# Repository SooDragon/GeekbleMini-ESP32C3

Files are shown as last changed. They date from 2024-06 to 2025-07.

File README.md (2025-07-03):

GeekbleMini-ESP32C3
=============
GeekbleMini-ESP32C3 문서에 오신것을 환영합니다

아두이노 IDE에서 쉽게 사용할 수 있는 Geekble Mini를 통해 WiFi, Bluetooth 기능을 여러분의 프로젝트에 구현할 수 있습니다

Geekble Mini 핀맵
-------------
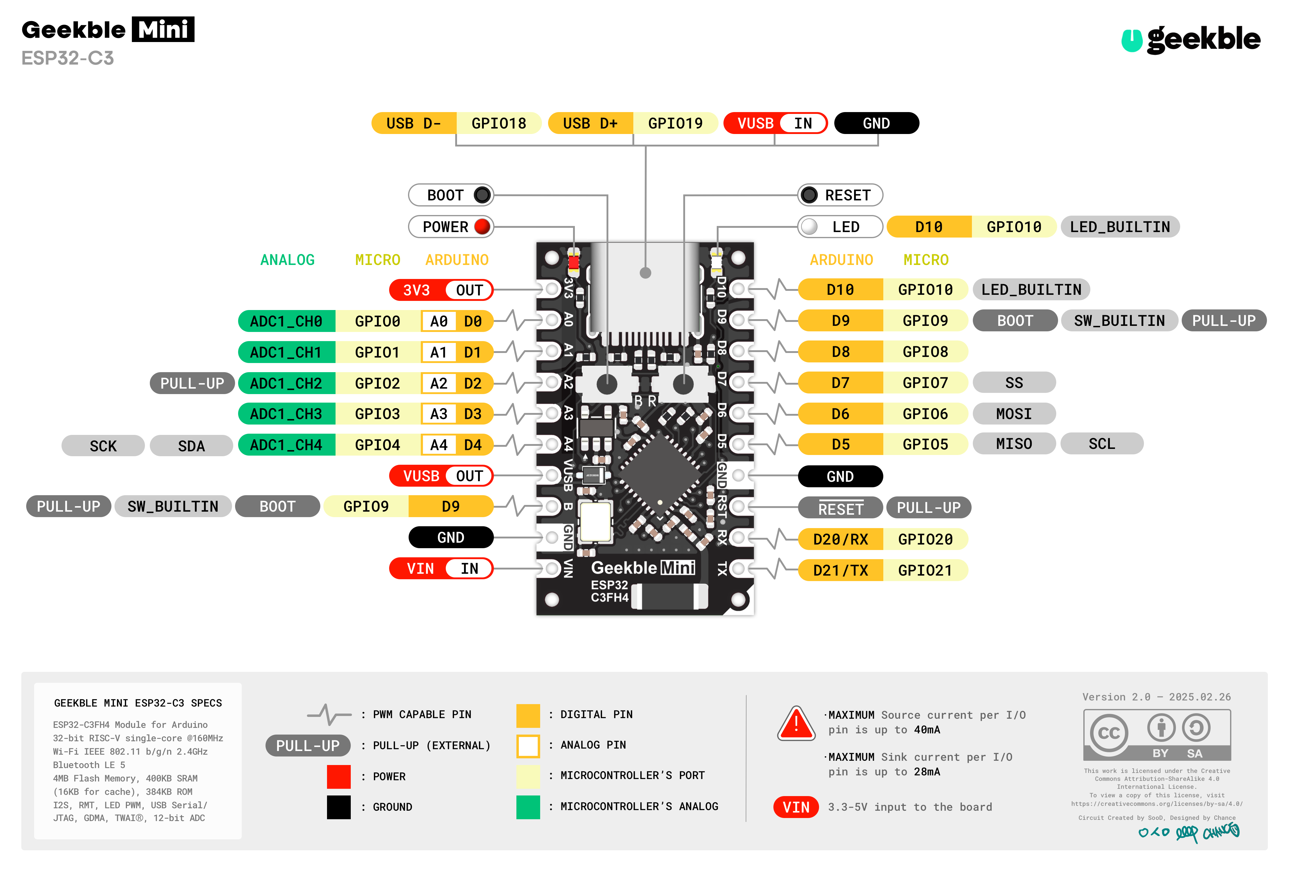
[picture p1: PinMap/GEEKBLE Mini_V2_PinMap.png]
GEEKBLE Mini-ESP32@2x

GeekbleMini PinMap

Geekble Mini 회로도
-------------
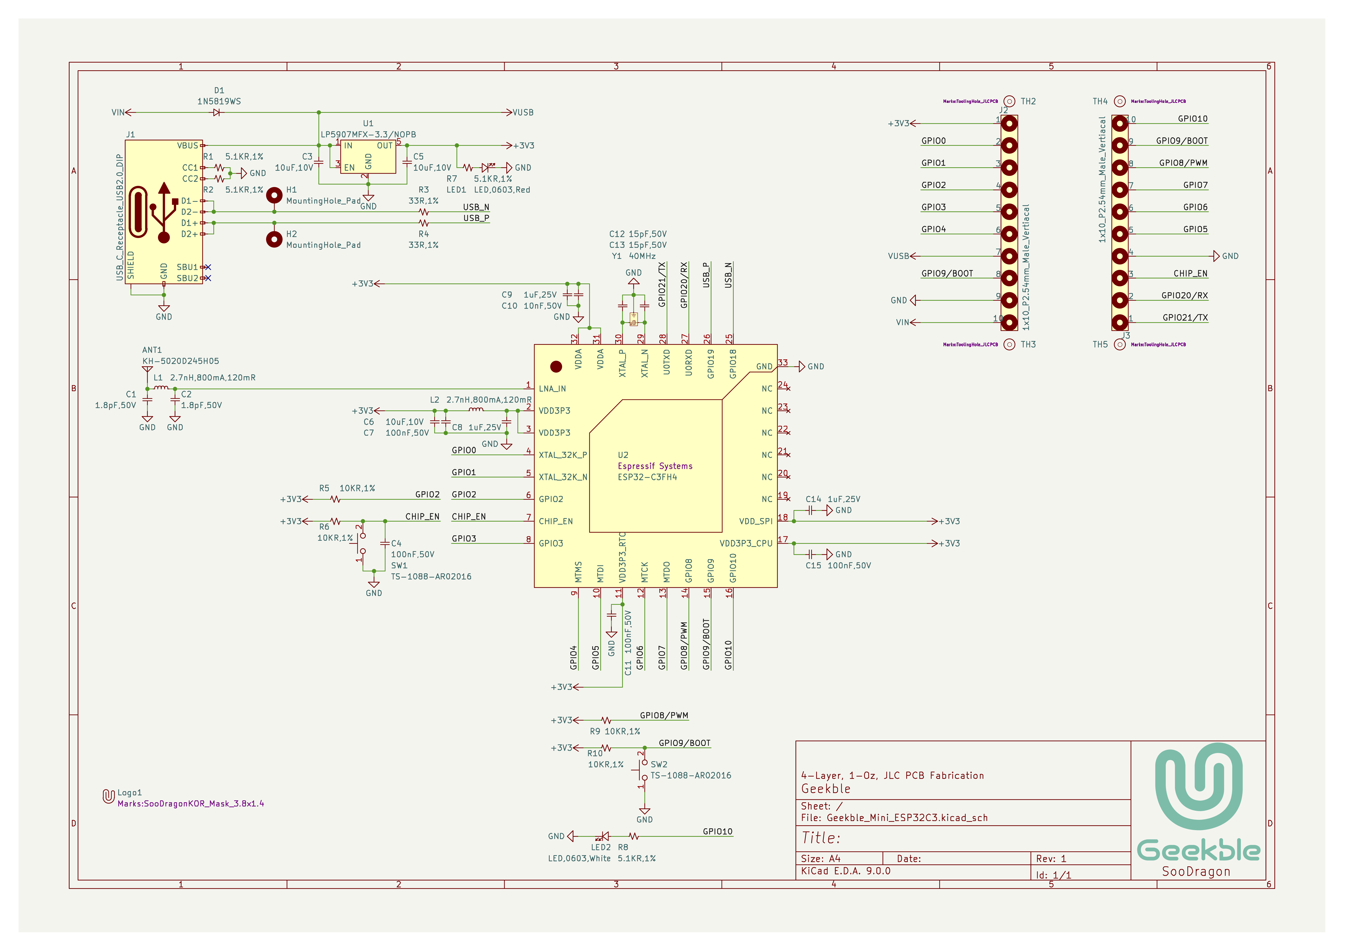
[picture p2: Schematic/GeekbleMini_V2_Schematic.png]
GeekbleMini Schematic

GeekbleMini Schematic

Geekble Mini 치수도
-------------
Dimension
GeekbleMini Dimension

Geekble Mini KiCad 라이브러리 by [@Alcyone-0022](https://github.com/Alcyone-0022)
-------------
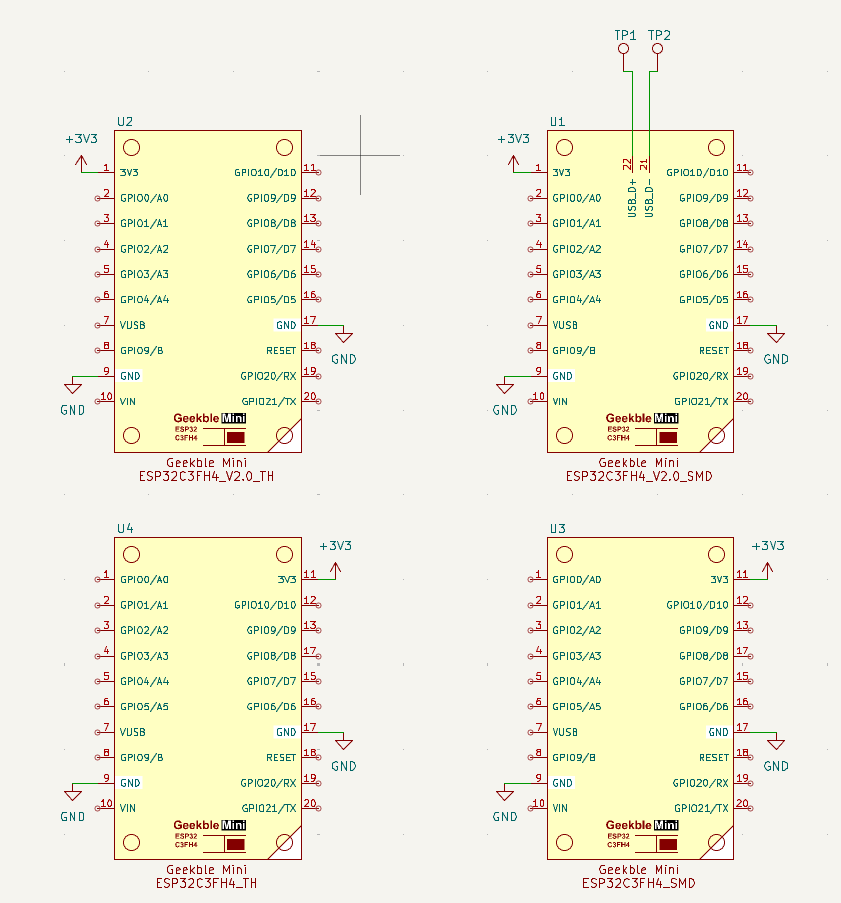
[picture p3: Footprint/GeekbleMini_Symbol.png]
Symbol
    
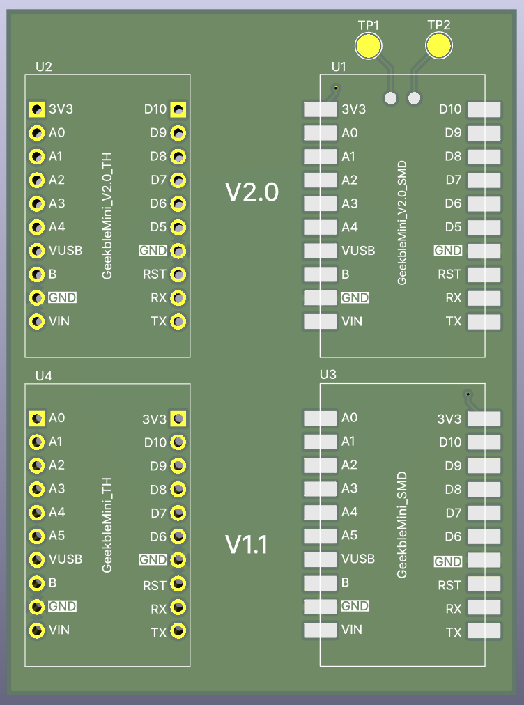
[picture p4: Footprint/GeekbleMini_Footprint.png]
Footprint
    
KiCad 프로젝트에 사용 가능한 Footprint가 존재합니다.    
**Geekble Mini ESP32C3FH4.pretty** 폴더와 **Geekble Mini ESP32C3FH4.kicad_sym** 파일을 KiCad 프로젝트 폴더에 옮긴 뒤,    
각각 풋프린트 에디터→파일→라이브러리 추가→프로젝트 선택→확인→**Geekble Mini ESP32C3FH4.pretty** 폴더 선택,    
심볼 에디터→파일→라이브러리 추가→프로젝트 선택→확인→**Geekble Mini ESP32C3FH4.kicad_sym** 파일 선택하여 추가하신 뒤 사용해 주세요.

Geekble Mini Version Log
-------------
- Ver.1.0.0: 최초 공개 버전
- Ver.1.1.0: Vin/VUSB 설계 변경, VUSB에서 Vin 방향으로 전류가 흐르지 않도록 회로 및 아트웍 수정, Vin에 배터리가 연결 된 상태에서 USB를 연결할 수 있다
- Ver.1.1.1: 핀헤더에 의해 실크가 가려지지 않게 배치 수정
- Ver.2.0: A5(ADC1)핀 D5핀으로 재배치, 재배치에 따른 핀 위치 수정

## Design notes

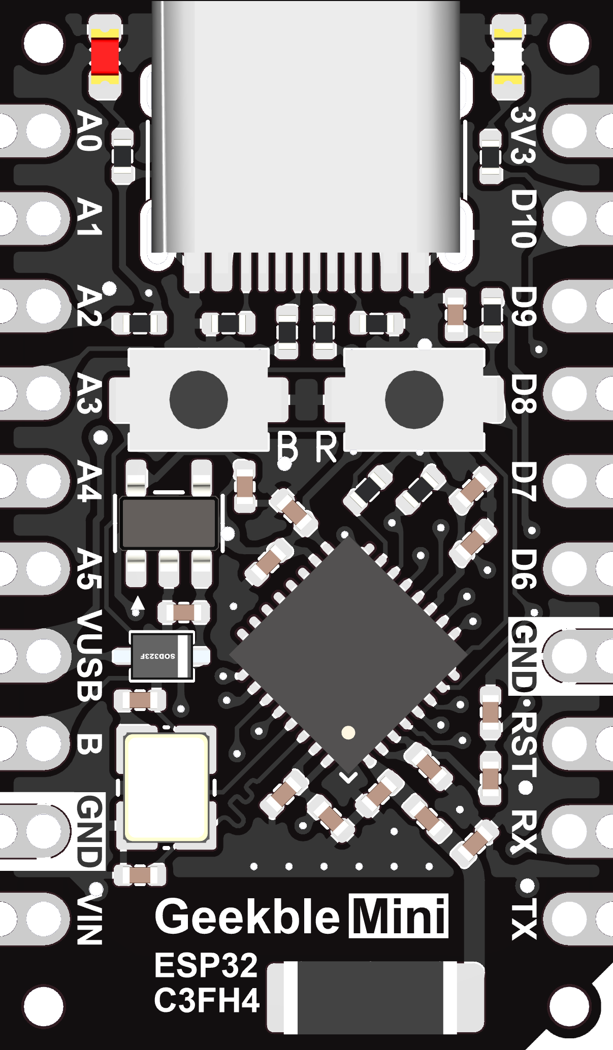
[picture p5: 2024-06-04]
GeekbleMini_V1_Diagram.png

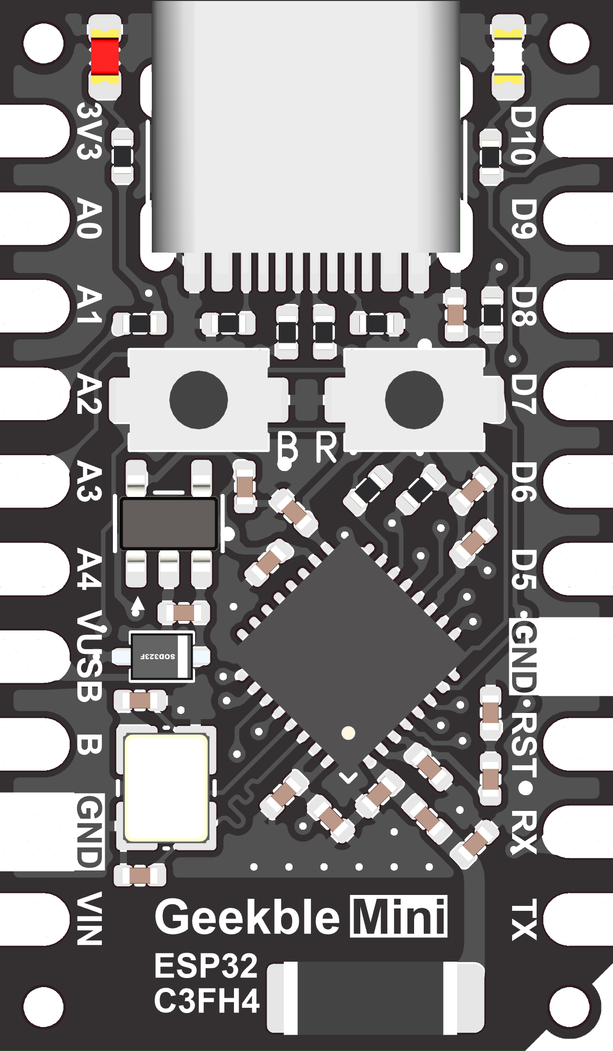
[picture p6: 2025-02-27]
Images/GeekbleMini_Ver.2.0_Diagram.png

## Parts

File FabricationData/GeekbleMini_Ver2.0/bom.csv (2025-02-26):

Designator | Footprint | Quantity | Value | LCSC Part #
ANT1 | ANT_5020 | 1 | KH-5020D245H05 | C45359218
C1, C2 | C_0402 | 2 | 1.8pF,50V | C327209
C10 | C_0402 | 1 | 10nF,50V | C15195
C11, C15, C4, C7 | C_0402 | 4 | 100nF,50V | C307331
C12, C13 | C_0402 | 2 | 15pF,50V | C1548
C14, C8, C9 | C_0402 | 3 | 1uF,25V | C52923
C3, C5, C6 | C_0402 | 3 | 10uF,10V | C386033
D1 | SOD-323F | 1 | 1N5819WS | C191023
H1, H2 | 1x1_1.0piPad_SMD | 2 | MountingHole_Pad
J1 | USB_DIP,8.94x7.3mm | 1 | USB_C_Receptacle_USB2.0_DIP | C165948
J2, J3 | 1x10_P2.54_CastellatedPad_PinHeader | 2 | 1x10_P2.54mm_Male_Vertiacal | C5383117
L1, L2 | L_0402 | 2 | 2.7nH,800mA,120mR | C77108
LED1 | LED_0603_Red | 1 | LED,0603,Red | C2286
LED2 | LED_0603_White | 1 | LED,0603,White | C2290
LOGO1 | SooDragonKOR_Mask_3.8x1.4 | 1 | Geekble_Logo
R1, R2, R7, R8 | R_0402 | 4 | 5.1KR,1% | C25905
R10, R5, R6, R9 | R_0402 | 4 | 10KR,1% | C25744
R3, R4 | R_0402 | 2 | 33R,1% | C25105
SW1, SW2 | TS-1088-AR020 | 2 | TS-1088-AR02016 | C720477
TH2, TH3, TH4, TH5 | ToolingHole_JLCPCB | 4 | ToolingHole
U1 | SOT-23-5 | 1 | LP5907MFX-3.3/NOPB | C80670
U2 | QFN-32-EP(5x5) | 1 | ESP32-C3FH4 | C2858491
Y1 | SMD-3225_4P | 1 | 40MHz | C9010

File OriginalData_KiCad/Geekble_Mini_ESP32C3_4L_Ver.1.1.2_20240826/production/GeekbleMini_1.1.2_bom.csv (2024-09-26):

Designator | Footprint | Quantity | Value | LCSC Part #
ANT1 | ANT_5020 | 1 | KH-5020D245M0X | C454142
C1, C2 | C_0402 | 2 | 1.8pF,50V | C327209
C10 | C_0402 | 1 | 10nF,50V | C15195
C11, C15, C4, C7 | C_0402 | 4 | 100nF,50V | C307331
C12, C13 | C_0402 | 2 | 15pF,50V | C1548
C14, C8, C9 | C_0402 | 3 | 1uF,25V | C52923
C3, C5, C6 | C_0402 | 3 | 10uF,10V | C386033
D1 | SOD-323F | 1 | 1N5819WS | C191023
J1 | USB_DIP,8.94x7.3mm | 1 | USB_C_Receptacle_USB2.0_DIP | C165948
L1, L2 | L_0402 | 2 | 2.7nH,500mA,100mR | C76791
LED1 | LED_0603_Red | 1 | LED,0603,Red | C2286
LED2 | LED_0603_White | 1 | LED,0603,White | C2290
R1, R2, R7, R8 | R_0402 | 4 | 5.1KR,1% | C25905
R10, R5, R6, R9 | R_0402 | 4 | 10KR,1% | C25744
R3, R4 | R_0402 | 2 | 33R,1% | C25105
SW1, SW2 | TS-1088-AR020 | 2 | TS-1088-AR02016 | C720477
U1 | SOT-23-5 | 1 | LP5907MFX-3.3/NOPB | C80670
U2 | QFN-32-EP(5x5) | 1 | ESP32-C3FH4 | C2858491
Y1 | SMD-3225_4P | 1 | 40MHz | C9010

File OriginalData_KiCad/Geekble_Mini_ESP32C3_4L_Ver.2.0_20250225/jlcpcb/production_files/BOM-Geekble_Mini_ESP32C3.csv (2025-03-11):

Comment | Designator | Footprint | LCSC | Quantity
10nF,50V | C10 | C_0402 | C15195 | 1
15pF,50V | C12,C13 | C_0402 | C1548 | 2
USB_C_Receptacle_USB2.0_DIP | J1 | USB_DIP,8.94x7.3mm | C165948 | 1
1N5819WS | D1 | SOD-323F | C191023 | 1
LED,0603,Red | LED1 | LED_0603_Red | C2286 | 1
LED,0603,White | LED2 | LED_0603_White | C2290 | 1
33R,1% | R3,R4 | R_0402 | C25105 | 2
10KR,1% | R10,R5,R6,R9 | R_0402 | C25744 | 4
5.1KR,1% | R1,R2,R7,R8 | R_0402 | C25905 | 4
ESP32-C3FH4 | U2 | QFN-32-EP(5x5) | C2858491 | 1
100nF,50V | C11,C15,C4,C7 | C_0402 | C307331 | 4
1.8pF,50V | C1,C2 | C_0402 | C327209 | 2
10uF,10V | C3,C5,C6 | C_0402 | C386033 | 3
KH-5020D245H05 | ANT1 | ANT_5020 | C45359218 | 1
1uF,25V | C14,C8,C9 | C_0402 | C52923 | 3
1x10_P2.54mm_Male_Vertiacal | J2,J3 | 1x10_P2.54_CastellatedPad_PinHeader | C5383117 | 2
TS-1088-AR02016 | SW1,SW2 | TS-1088-AR020 | C720477 | 2
2.7nH,800mA,120mR | L1,L2 | L_0402 | C77108 | 2
LP5907MFX-3.3/NOPB | U1 | SOT-23-5 | C80670 | 1
40MHz | Y1 | SMD-3225_4P | C9010 | 1
ToolingHole | TH4 | ToolingHole_JLCPCB |  | 1
ToolingHole | TH5 | ToolingHole_JLCPCB |  | 1
Geekble_Logo | Logo1 | SooDragonKOR_Mask_3.8x1.4 |  | 1
ToolingHole | TH3 | ToolingHole_JLCPCB |  | 1
ToolingHole | TH2 | ToolingHole_JLCPCB |  | 1
MountingHole_Pad | H2 | 1x1_1.0piPad_SMD |  | 1
MountingHole_Pad | H1 | 1x1_1.0piPad_SMD |  | 1

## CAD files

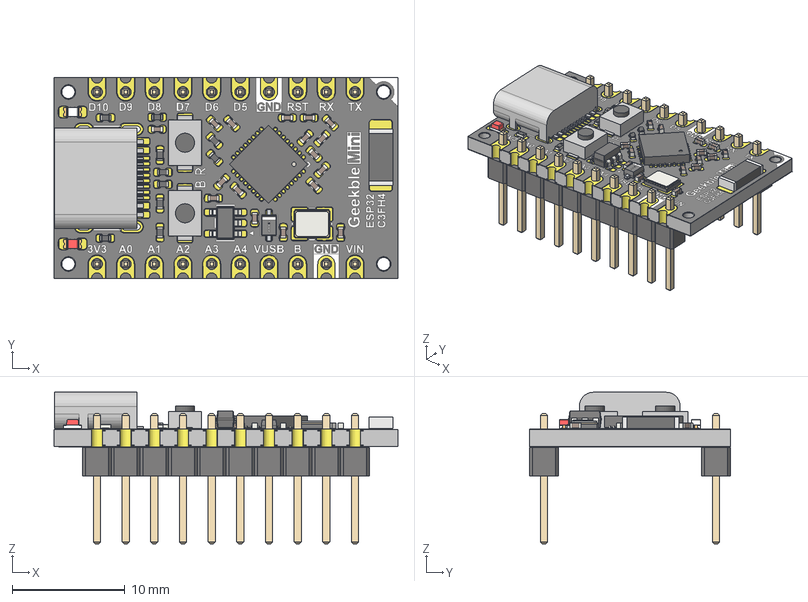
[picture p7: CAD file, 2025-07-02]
3D Model/GeekbleMini Ver2.0_PinHeader.step
30.5 x 17.8 x 13.4 mm
LED0603_WHITE
C_0402_1005Metric x 17
R_0402_1005Metric x 10
TS-1088-AR020 v2 x 2
QFN-32-1EP_5x5mm_P0.5mm_EP3.65x3.65mm
SOT-23-5
ANT_2050
SOD323F
HRO TYPE-C-31-M-12
Crystal_SMD_3225-4Pin_3.2x2.5mm
LED0603_RED
PinHeader_1x10_P2.54mm_Vertical x 2
Geekble_Mini_ESP32C3_copper
Geekble_Mini_ESP32C3_silkscreen
Geekble_Mini_ESP32C3_soldermask
Geekble_Mini_ESP32C3_PCB

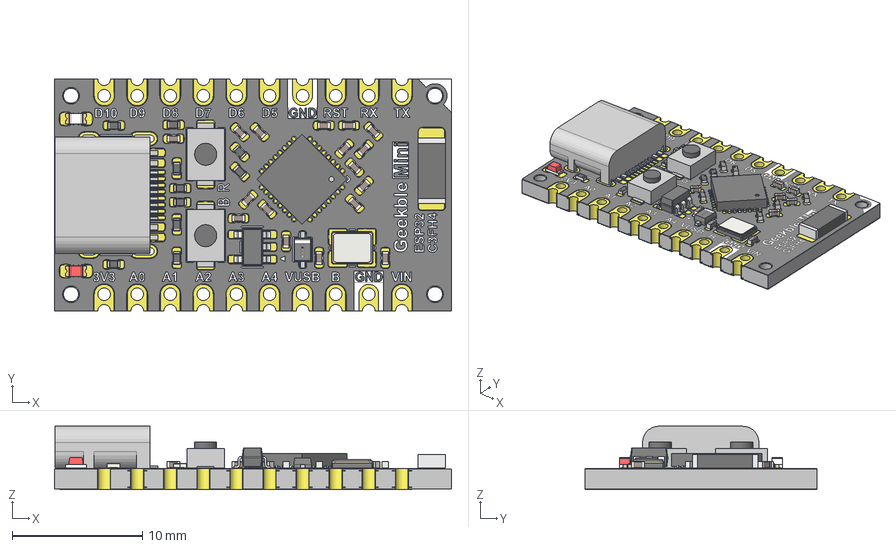
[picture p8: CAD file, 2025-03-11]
Footprint/GeekbleMini Ver2.0.step
30.5 x 17.8 x 4.89 mm
LED0603_WHITE
C_0402_1005Metric x 17
R_0402_1005Metric x 10
TS-1088-AR020 v2 x 2
QFN-32-1EP_5x5mm_P0.5mm_EP3.65x3.65mm
SOT-23-5
ANT_2050
SOD323F
HRO TYPE-C-31-M-12
Crystal_SMD_3225-4Pin_3.2x2.5mm
LED0603_RED
Geekble_Mini_ESP32C3_copper
Geekble_Mini_ESP32C3_silkscreen
Geekble_Mini_ESP32C3_soldermask
Geekble_Mini_ESP32C3_PCB

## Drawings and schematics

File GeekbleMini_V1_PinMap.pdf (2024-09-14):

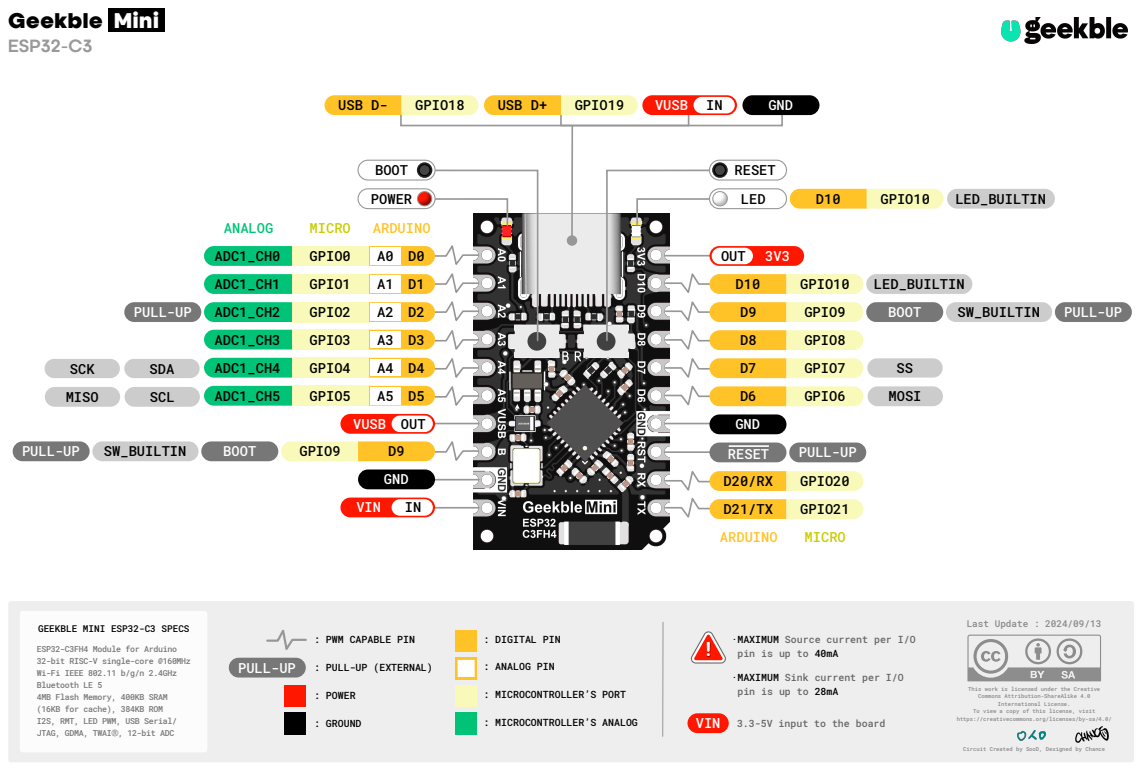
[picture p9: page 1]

GEEKBLE MINI ESP32-C3 SPECS
ESP32-C3FH4 Module for Arduino
32-bit RISC-V single-core @160MHz
Wi-Fi IEEE 802.11 b/g/n 2.4GHz
Bluetooth LE 5
4MB Flash Memory, 400KB SRAM
(16KB for cache), 384KB ROM
I2S, RMT, LED PWM, USB Serial/
JTAG, GDMA, TWAIⓇ, 12-bit ADC

·MAXIMUM Source current per I/O
pin is up to 40mA

·MAXIMUM Sink current per I/O
pin is up to 28mA

This work is licensed under the Creative
Commons Attribution-ShareAlike 4.0
International License.

To view a copy of this license, visit
https://creativecommons.org/licenses/by-sa/4.0/

Circuit Created by SooD, Designed by Chance

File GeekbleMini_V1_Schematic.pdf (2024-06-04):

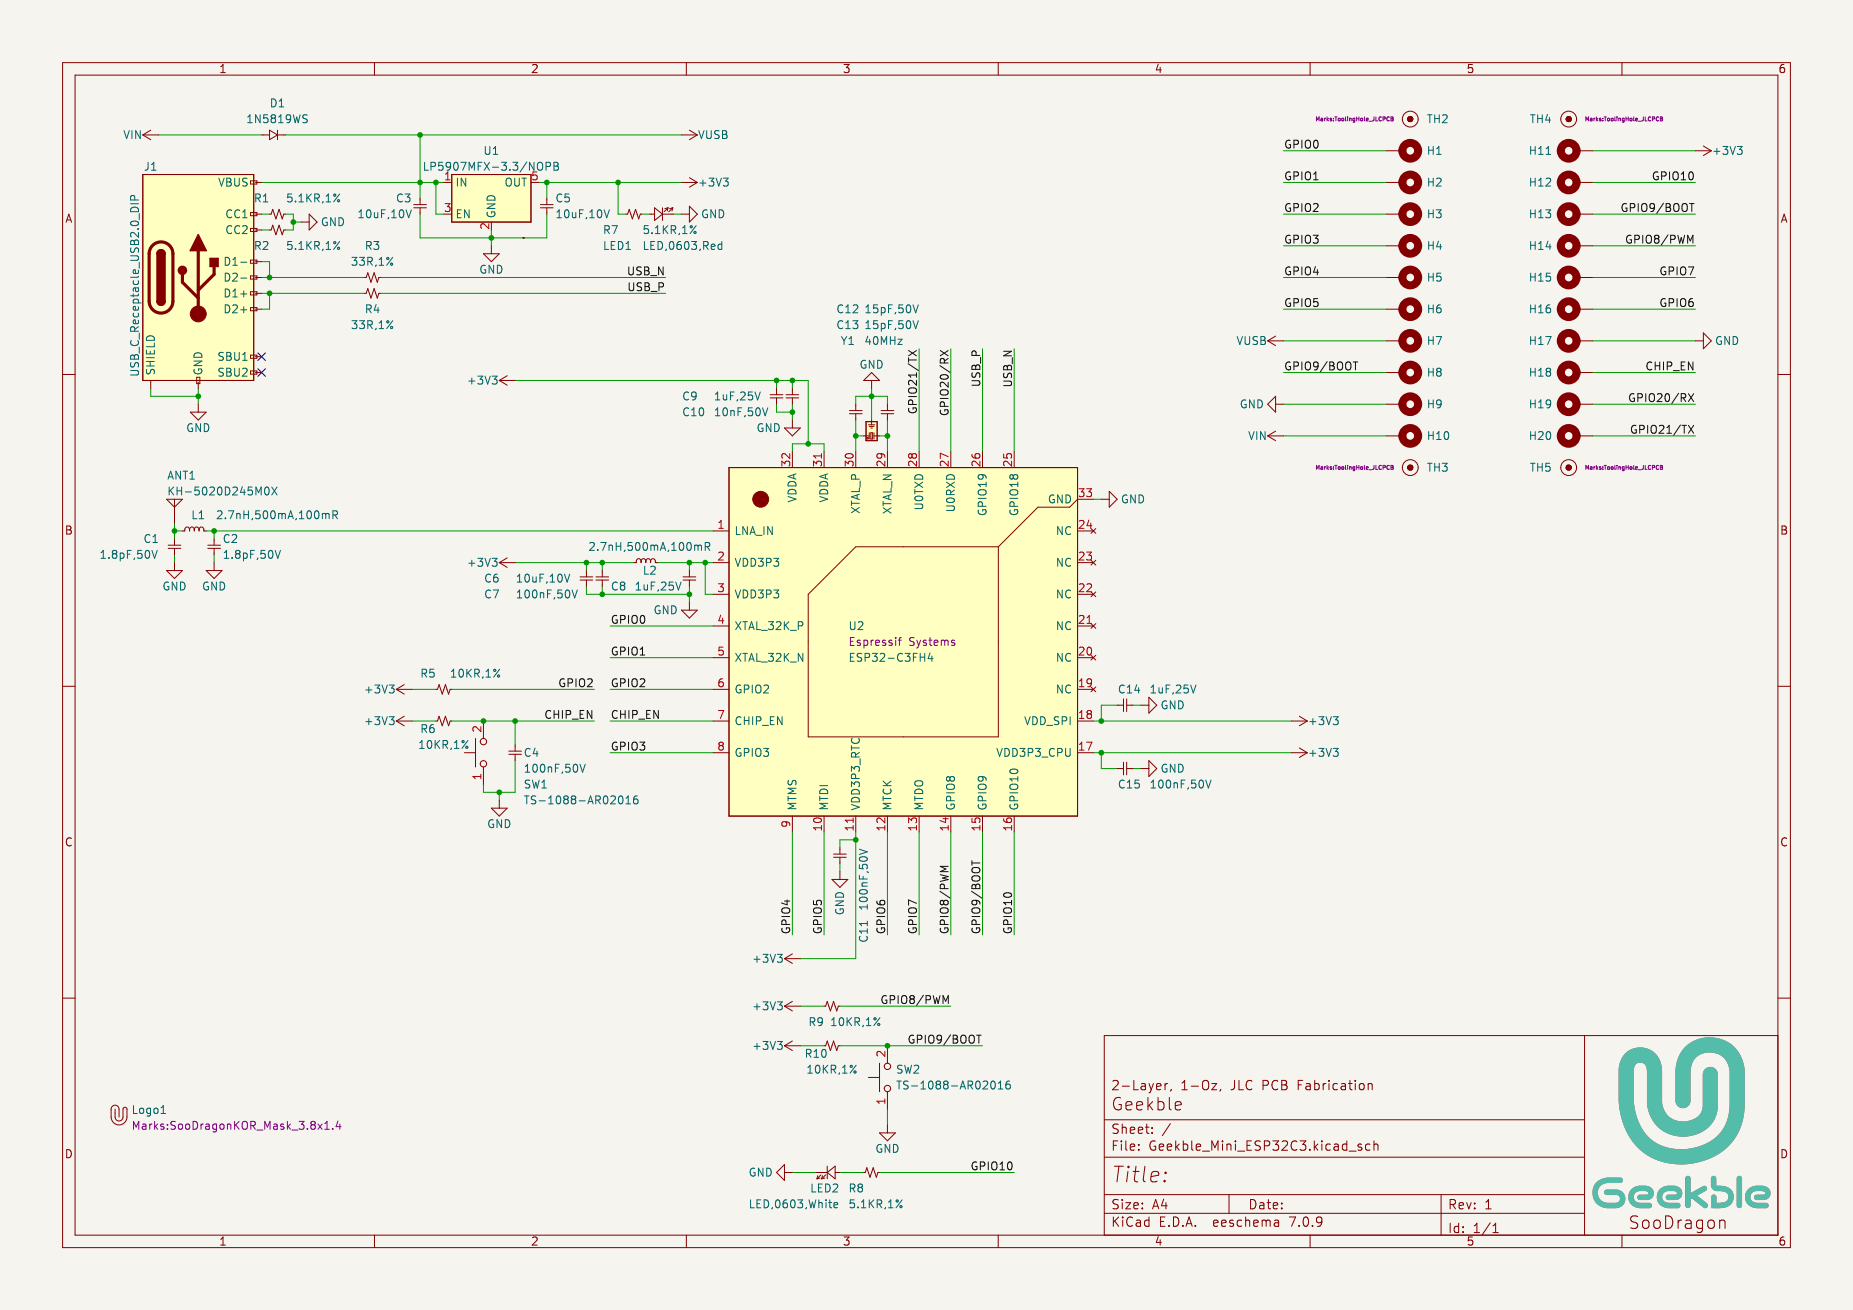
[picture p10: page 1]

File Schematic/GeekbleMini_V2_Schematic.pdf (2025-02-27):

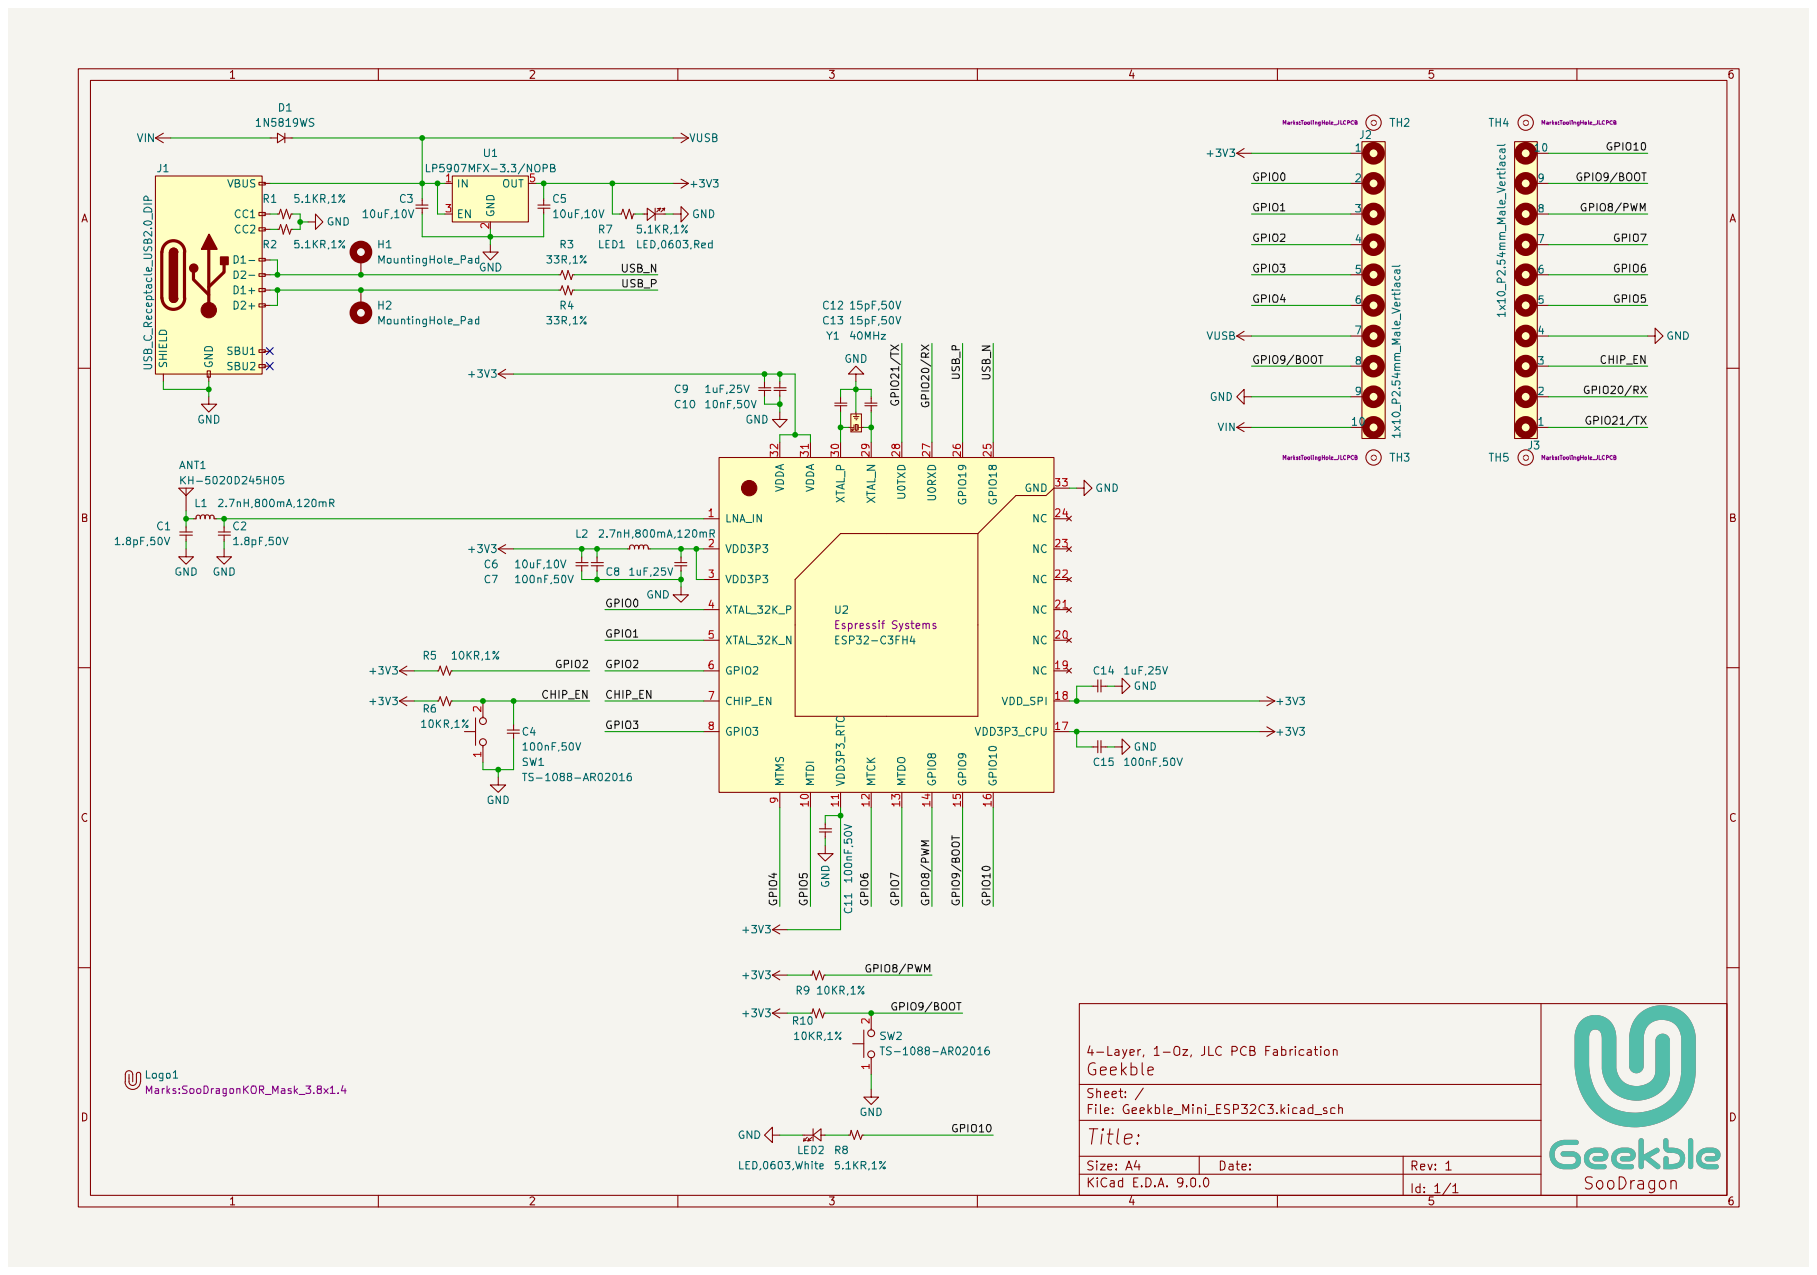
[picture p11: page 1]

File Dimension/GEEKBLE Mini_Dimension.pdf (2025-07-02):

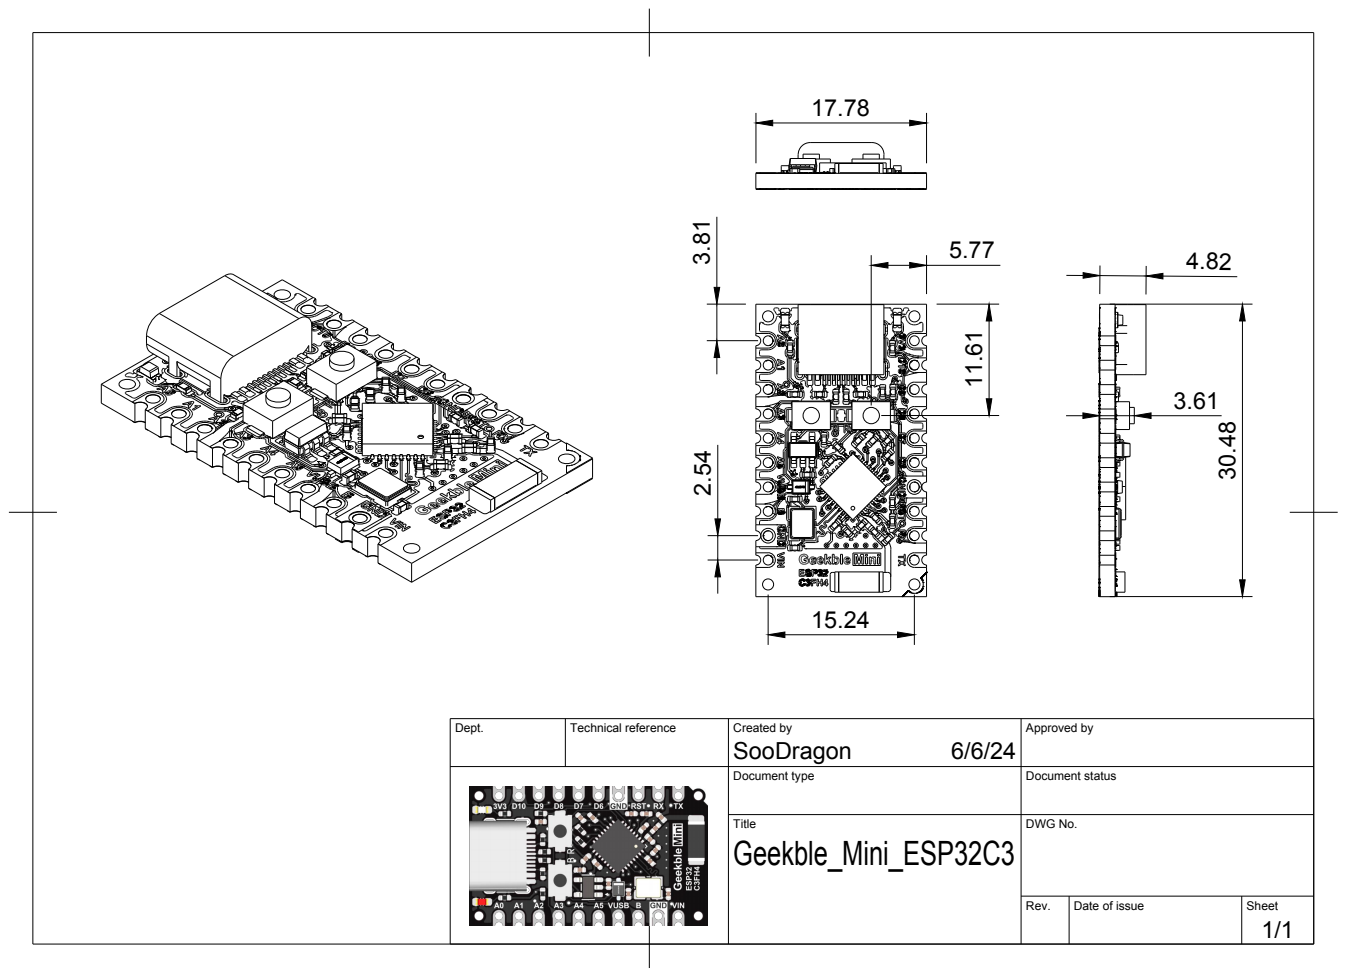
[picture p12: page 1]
Dept.; Technical reference; Created by; Approved by; Document type; Document status; Title; DWG No.; Rev.; Date of issue; Sheet

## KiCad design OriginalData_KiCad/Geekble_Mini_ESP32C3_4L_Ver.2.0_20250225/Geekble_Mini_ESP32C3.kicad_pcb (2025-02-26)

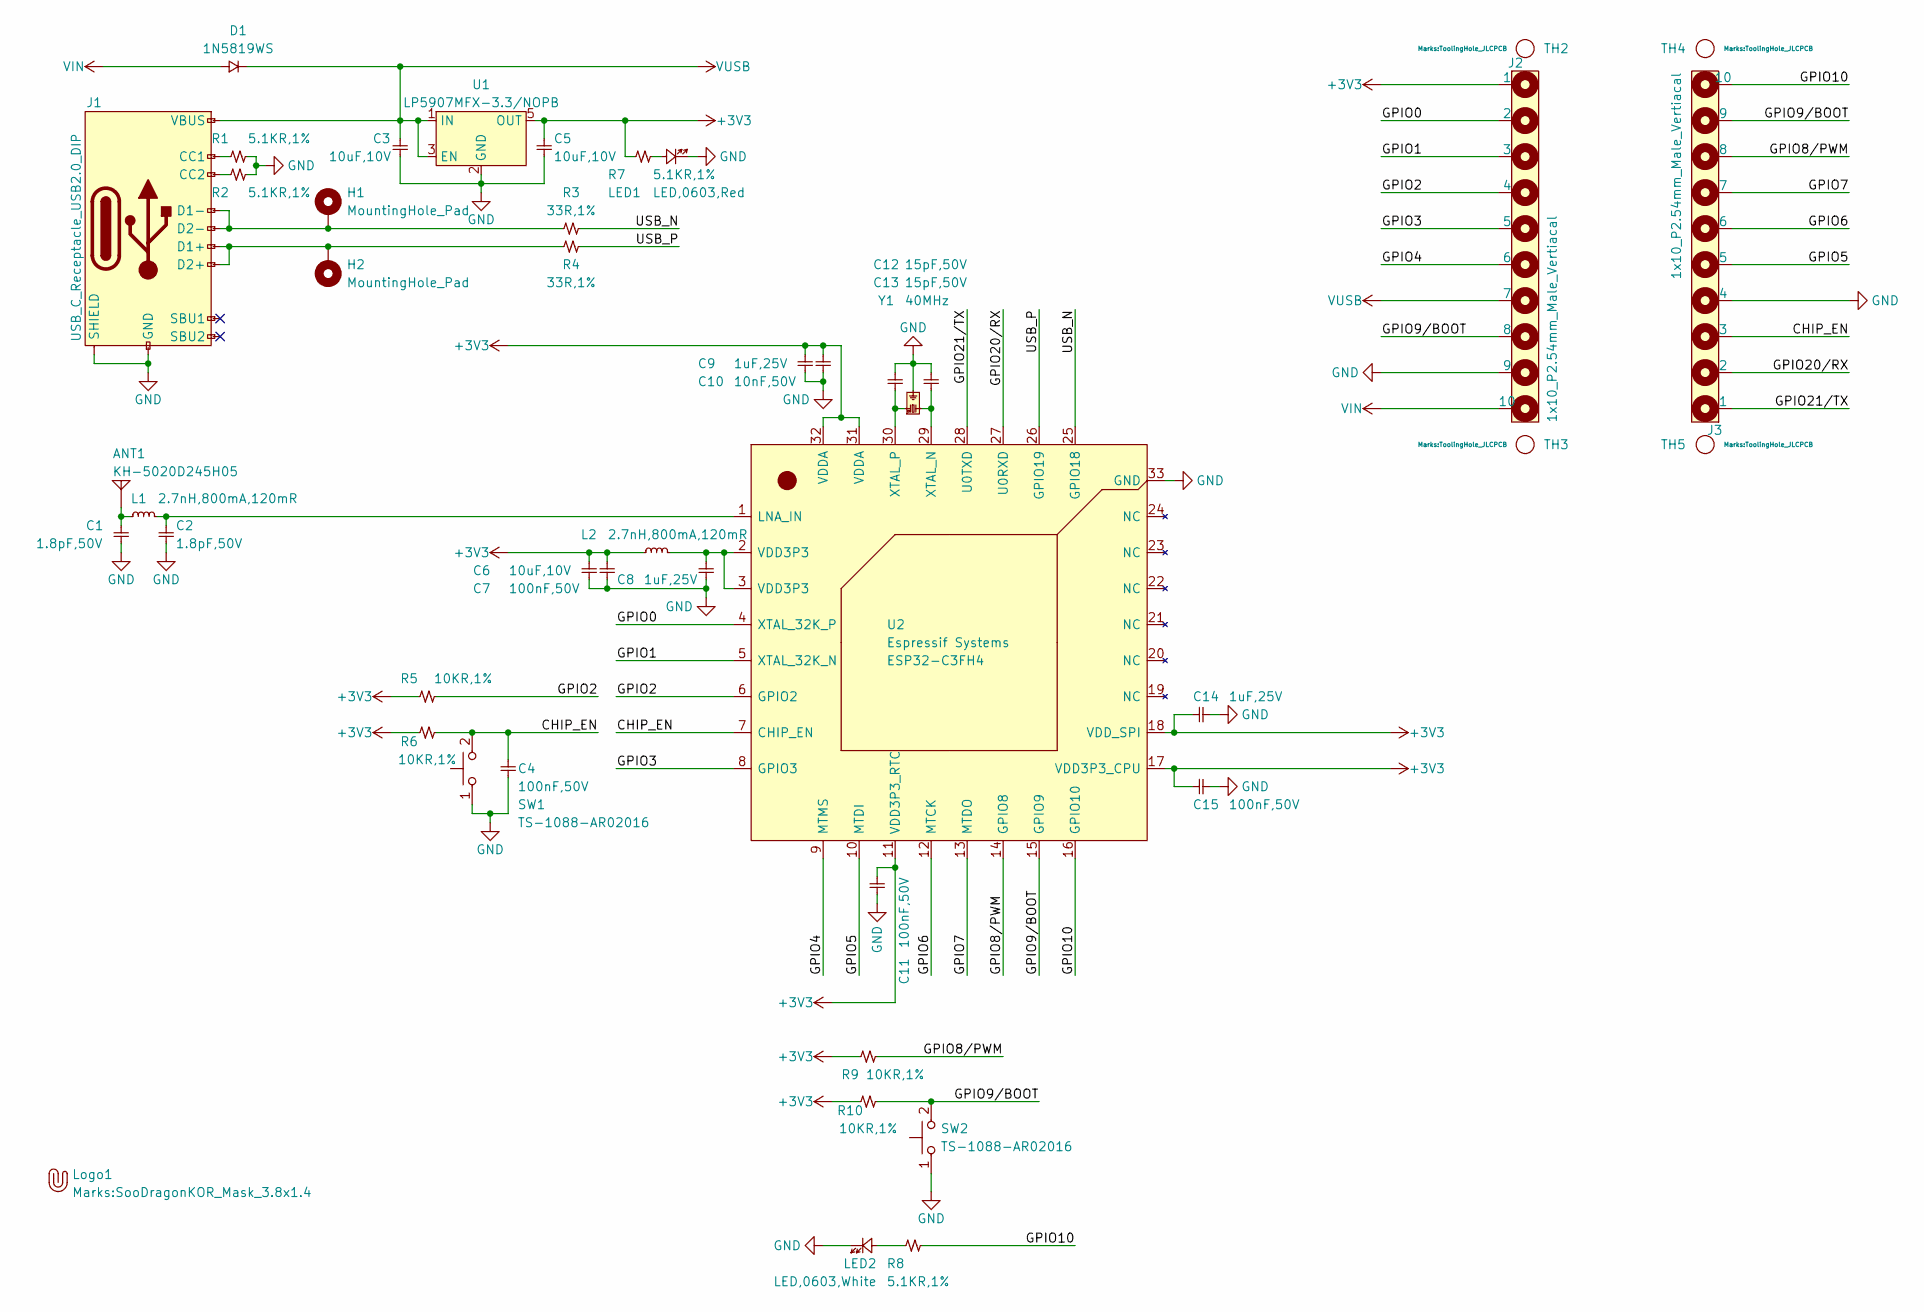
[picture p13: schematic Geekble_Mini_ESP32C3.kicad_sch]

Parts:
ANT1: KH-5020D245H05; ANT_5020; Manufacturer Part Number KH-5020D245H05; LCSC C45359218
C1, C2: 1.8pF,50V; C_0402; Manufacturer Part Number CC0402BRNPO9BN1R8; LCSC C327209
C3, C5, C6: 10uF,10V; C_0402; Manufacturer Part Number LDK105CBJ106MVLF; LCSC C386033
C4, C7, C11, C15: 100nF,50V; C_0402; Manufacturer Part Number CL05B104KB54PNC; LCSC C307331
C8, C9, C14: 1uF,25V; C_0402; Manufacturer Part Number CL05A105KA5NQNC; LCSC C52923
C10: 10nF,50V; C_0402; Manufacturer Part Number CL05B103KB5NNNC; LCSC C15195
C12, C13: 15pF,50V; C_0402; Manufacturer Part Number 0402CG150J500NT; LCSC C1548
D1: 1N5819WS; SOD-323F; Manufacturer Part Number 1N5819WS; LCSC C191023
H1, H2: MountingHole_Pad; 1x1_1.0piPad_SMD
J1: USB_C_Receptacle_USB2.0_DIP; USB_DIP,8.94x7.3mm; Manufacturer Part Number TYPE-C-31-M-12; LCSC C165948
J2, J3: 1x10_P2.54mm_Male_Vertiacal; 1x10_P2.54_CastellatedPad_PinHeader; Manufacturer Part Number 2541WV-10P; LCSC C5383117
L1, L2: 2.7nH,800mA,120mR; L_0402; Manufacturer Part Number LQG15HS2N7S02D; LCSC C77108
LED1: LED,0603,Red; LED_0603_Red; Manufacturer Part Number KT-0603R; LCSC C2286
LED2: LED,0603,White; LED_0603_White; LCSC C2290
Logo1: Geekble_Logo; SooDragonKOR_Mask_3.8x1.4
R1, R2, R7, R8: 5.1KR,1%; R_0402; Manufacturer Part Number 0402WGF5101TCE; LCSC C25905
R3, R4: 33R,1%; R_0402; Manufacturer Part Number 0402WGF330JTCE; LCSC C25105
R5, R6, R9, R10: 10KR,1%; R_0402; Manufacturer Part Number 0402WGF1002TCE; LCSC C25744
SW1, SW2: TS-1088-AR02016; TS-1088-AR020; Manufacturer Part Number TS-1088-AR02016; LCSC C720477
TH2, TH3, TH4, TH5: ToolingHole; ToolingHole_JLCPCB
U1: LP5907MFX-3.3/NOPB; SOT-23-5; Manufacturer Part Number LP5907MFX-3.3/NOPB; LCSC C80670
U2: ESP32-C3FH4; QFN-32-EP(5x5); Manufacturer Part Number ESP32-C3FH4; LCSC C2858491
Y1: 40MHz; SMD-3225_4P; Manufacturer Part Number X322540MPB4SI; LCSC C9010

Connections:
+3V3: C5.2, C6.2, C7.2, C9.2, C10.2, C11.2, C14.2, C15.2, J2.1, L2.1, R5.1, R6.1, R7.1, R9.1, R10.1, U1.5 (OUT), U2.11 (VDD3P3_RTC), U2.17 (VDD3P3_CPU), U2.18 (VDD_SPI), U2.31 (VDDA), U2.32 (VDDA)
/CHIP_EN: C4.2, J3.3, R6.2, SW1.2 (B), U2.7 (CHIP_EN)
/GPIO0: J2.2, U2.4 (XTAL_32K_P)
/GPIO1: J2.3, U2.5 (XTAL_32K_N)
/GPIO2: J2.4, R5.2, U2.6 (GPIO2)
/GPIO3: J2.5, U2.8 (GPIO3)
/GPIO4: J2.6, U2.9 (MTMS)
/GPIO5: J3.5, U2.10 (MTDI)
/GPIO6: J3.6, U2.12 (MTCK)
/GPIO7: J3.7, U2.13 (MTDO)
/GPIO8/PWM: J3.8, R9.2, U2.14 (GPIO8)
/GPIO9/BOOT: J2.8, J3.9, R10.2, SW2.2 (B), U2.15 (GPIO9)
/GPIO10: J3.10, R8.2, U2.16 (GPIO10)
/GPIO20/RX: J3.2, U2.27 (U0RXD)
/GPIO21/TX: J3.1, U2.28 (U0TXD)
/USB_N: R3.2, U2.25 (GPIO18)
/USB_P: R4.2, U2.26 (GPIO19)
GND: C1.1, C2.1, C3.1, C4.1, C5.1, C6.1, C7.1, C8.1, C9.1, C10.1, C11.1, C12.1, C13.1, C14.1, C15.1, J1.A1B12 (GND), J1.B1A12 (GND), J1.S1 (SHIELD), J1.S2 (SHIELD), J1.S3 (SHIELD), J1.S4 (SHIELD), J2.9, J3.4, LED1.C, LED2.C, R1.2, R2.2, SW1.1 (A), SW2.1 (A), U1.2 (GND), U2.33 (GND), Y1.2 (GND), Y1.4 (GND)
unnamed: ANT1.Feed, C1.2, L1.1
unnamed: C8.2, L2.2, U2.2 (VDD3P3), U2.3 (VDD3P3)
unnamed: J1.A5 (CC1), R1.1
unnamed: J1.B5 (CC2), R2.1
unnamed: H2.1, J1.A6 (D1+), J1.B6 (D2+), R4.1
unnamed: H1.1, J1.A7 (D1-), J1.B7 (D2-), R3.1
unnamed: LED1.A, R7.2
unnamed: LED2.A, R8.1
unnamed: C2.2, L1.2, U2.1 (LNA_IN)
unnamed: C13.2, U2.29 (XTAL_N), Y1.3 (OSC2)
unnamed: C12.2, U2.30 (XTAL_P), Y1.1 (OSC1)
VIN: D1.A, J2.10
VUSB: C3.2, D1.C, J1.A4B9 (VBUS), J1.B4A9 (VBUS), J2.7, U1.1 (IN), U1.3 (EN)

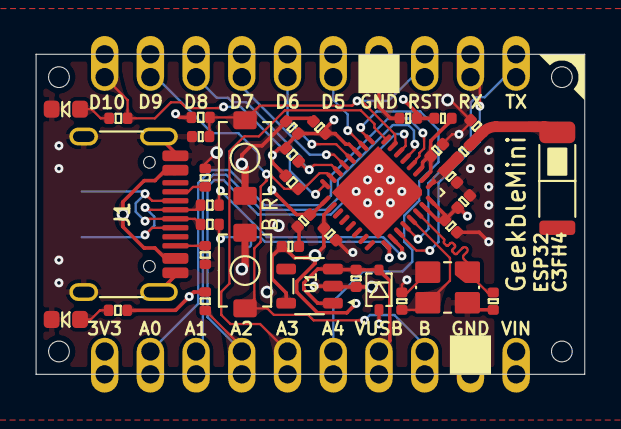
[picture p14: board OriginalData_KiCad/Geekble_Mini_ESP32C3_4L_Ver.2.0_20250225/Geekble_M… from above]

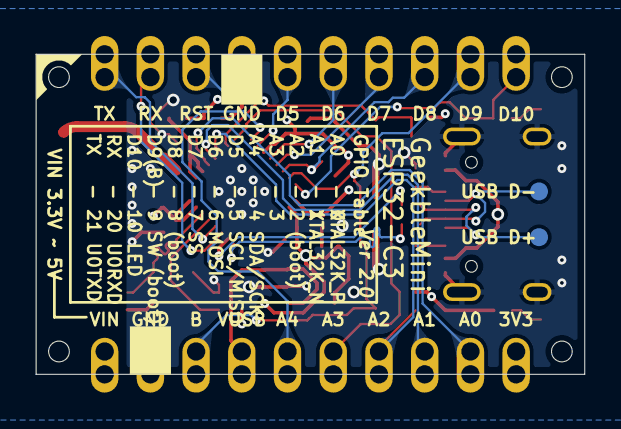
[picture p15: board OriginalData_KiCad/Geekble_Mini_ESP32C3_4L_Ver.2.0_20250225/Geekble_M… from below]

Board: 4 copper layers, 30.5 x 17.8 mm, 46 parts (4 on the bottom side), 31 nets.

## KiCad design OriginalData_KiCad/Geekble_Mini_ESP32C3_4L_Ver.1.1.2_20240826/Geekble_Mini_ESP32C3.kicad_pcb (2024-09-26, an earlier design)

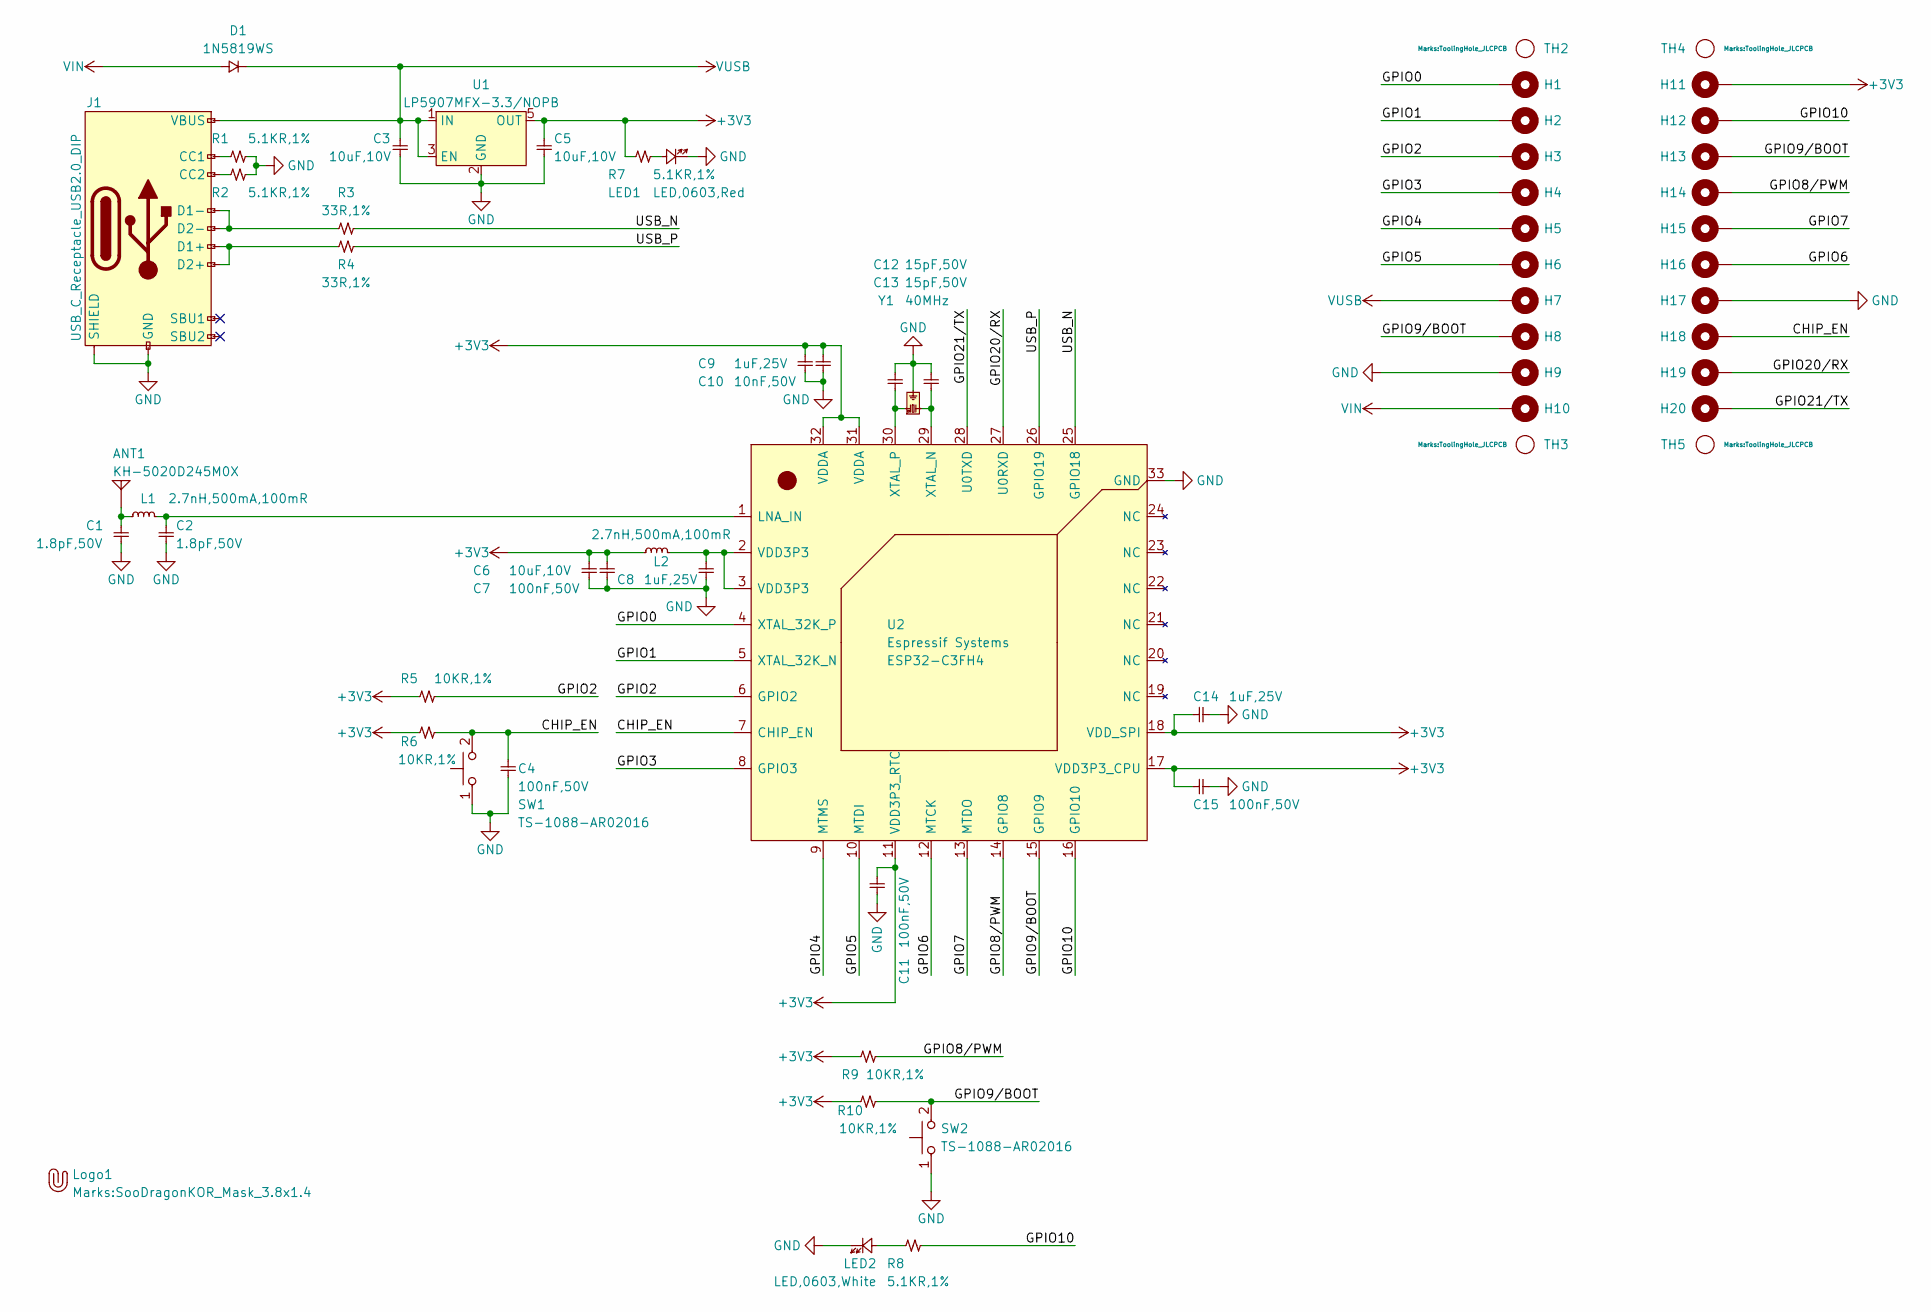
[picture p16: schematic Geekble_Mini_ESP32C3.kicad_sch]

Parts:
ANT1: KH-5020D245M0X; ANT_5020; Manufacturer Part Number KH-5020D245M0X; LCSC C454142
C1, C2: 1.8pF,50V; C_0402; Manufacturer Part Number CC0402BRNPO9BN1R8; LCSC C327209
C3, C5, C6: 10uF,10V; C_0402; Manufacturer Part Number LDK105CBJ106MVLF; LCSC C386033
C4, C7, C11, C15: 100nF,50V; C_0402; Manufacturer Part Number CL05B104KB54PNC; LCSC C307331
C8, C9, C14: 1uF,25V; C_0402; Manufacturer Part Number CL05A105KA5NQNC; LCSC C52923
C10: 10nF,50V; C_0402; Manufacturer Part Number CL05B103KB5NNNC; LCSC C15195
C12, C13: 15pF,50V; C_0402; Manufacturer Part Number 0402CG150J500NT; LCSC C1548
D1: 1N5819WS; SOD-323F; Manufacturer Part Number 1N5819WS; LCSC C191023
H1, H2, H3, H4, H5, H6, H7, H8, H9, H10, H11, H12, H13, H14, H15, H16, H17, H18, H19, H20: MountingHole_Pad; 1x1_P2.54_CastellatedPad
J1: USB_C_Receptacle_USB2.0_DIP; USB_DIP,8.94x7.3mm; Manufacturer Part Number TYPE-C-31-M-12; LCSC C165948
L1, L2: 2.7nH,500mA,100mR; L_0402; Manufacturer Part Number MLK1005S2N7ST000; LCSC C76791
LED1: LED,0603,Red; LED_0603_Red; Manufacturer Part Number KT-0603R; LCSC C2286
LED2: LED,0603,White; LED_0603_White; LCSC C2290
Logo1: Geekble_Logo; SooDragonKOR_Mask_3.8x1.4
R1, R2, R7, R8: 5.1KR,1%; R_0402; Manufacturer Part Number 0402WGF5101TCE; LCSC C25905
R3, R4: 33R,1%; R_0402; Manufacturer Part Number 0402WGF330JTCE; LCSC C25105
R5, R6, R9, R10: 10KR,1%; R_0402; Manufacturer Part Number 0402WGF1002TCE; LCSC C25744
SW1, SW2: TS-1088-AR02016; TS-1088-AR020; Manufacturer Part Number TS-1088-AR02016; LCSC C720477
TH2, TH3, TH4, TH5: ToolingHole; ToolingHole_JLCPCB
U1: LP5907MFX-3.3/NOPB; SOT-23-5; Manufacturer Part Number LP5907MFX-3.3/NOPB; LCSC C80670
U2: ESP32-C3FH4; QFN-32-EP(5x5); Manufacturer Part Number ESP32-C3FH4; LCSC C2858491
Y1: 40MHz; SMD-3225_4P; Manufacturer Part Number X322540MPB4SI; LCSC C9010

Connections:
+3V3: C5.2, C6.2, C7.2, C9.2, C10.2, C11.2, C14.2, C15.2, H11.1, L2.1, R5.1, R6.1, R7.1, R9.1, R10.1, U1.5 (OUT), U2.11 (VDD3P3_RTC), U2.17 (VDD3P3_CPU), U2.18 (VDD_SPI), U2.31 (VDDA), U2.32 (VDDA)
/CHIP_EN: C4.2, H18.1, R6.2, SW1.2 (B), U2.7 (CHIP_EN)
/GPIO0: H1.1, U2.4 (XTAL_32K_P)
/GPIO1: H2.1, U2.5 (XTAL_32K_N)
/GPIO2: H3.1, R5.2, U2.6 (GPIO2)
/GPIO3: H4.1, U2.8 (GPIO3)
/GPIO4: H5.1, U2.9 (MTMS)
/GPIO5: H6.1, U2.10 (MTDI)
/GPIO6: H16.1, U2.12 (MTCK)
/GPIO7: H15.1, U2.13 (MTDO)
/GPIO8/PWM: H14.1, R9.2, U2.14 (GPIO8)
/GPIO9/BOOT: H8.1, H13.1, R10.2, SW2.2 (B), U2.15 (GPIO9)
/GPIO10: H12.1, R8.2, U2.16 (GPIO10)
/GPIO20/RX: H19.1, U2.27 (U0RXD)
/GPIO21/TX: H20.1, U2.28 (U0TXD)
/USB_N: R3.2, U2.25 (GPIO18)
/USB_P: R4.2, U2.26 (GPIO19)
GND: C1.1, C2.1, C3.1, C4.1, C5.1, C6.1, C7.1, C8.1, C9.1, C10.1, C11.1, C12.1, C13.1, C14.1, C15.1, H9.1, H17.1, J1.A1B12 (GND), J1.B1A12 (GND), J1.S1 (SHIELD), J1.S2 (SHIELD), J1.S3 (SHIELD), J1.S4 (SHIELD), LED1.C, LED2.C, R1.2, R2.2, SW1.1 (A), SW2.1 (A), U1.2 (GND), U2.33 (GND), Y1.2 (GND), Y1.4 (GND)
unnamed: ANT1.Feed, C1.2, L1.1
unnamed: C8.2, L2.2, U2.2 (VDD3P3), U2.3 (VDD3P3)
unnamed: J1.A5 (CC1), R1.1
unnamed: J1.B5 (CC2), R2.1
unnamed: J1.A6 (D1+), J1.B6 (D2+), R4.1
unnamed: J1.A7 (D1-), J1.B7 (D2-), R3.1
unnamed: LED1.A, R7.2
unnamed: LED2.A, R8.1
unnamed: C2.2, L1.2, U2.1 (LNA_IN)
unnamed: C13.2, U2.29 (XTAL_N), Y1.3 (OSC2)
unnamed: C12.2, U2.30 (XTAL_P), Y1.1 (OSC1)
VIN: D1.A, H10.1
VUSB: C3.2, D1.C, H7.1, J1.A4B9 (VBUS), J1.B4A9 (VBUS), U1.1 (IN), U1.3 (EN)

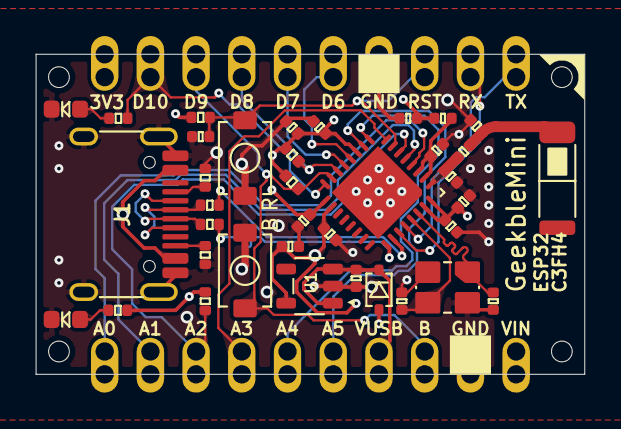
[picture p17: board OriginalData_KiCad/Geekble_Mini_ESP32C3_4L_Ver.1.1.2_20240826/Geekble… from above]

Board: 4 copper layers, 30.5 x 17.8 mm, 62 parts (0 on the bottom side), 31 nets.

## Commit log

2024-06-04 DataUpload
    DataUpload
    [GeekbleMiniESP32C3_1.1.0_BOM.csv, GeekbleMini_1.1.1_BOM.csv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]
2024-09-26 1.1.2 update
    1.1.2 update
    [GeekbleMini_1.1.2_bom.csv, GeekbleMini_1.1.2_designators.csv, GeekbleMini_1.1.2_positions.csv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]
2025-02-27 V2 SCH
    [Geekble_Mini_ESP32C3.kicad_sch]
2025-03-11 add geekblemini kicad lib
    [BOM-Geekble_Mini_ESP32C3.csv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]
2025-07-02 ud
    ud
    [GeekbleMini Ver2.0.step, GeekbleMini Ver2.0_PinHeader.step]
